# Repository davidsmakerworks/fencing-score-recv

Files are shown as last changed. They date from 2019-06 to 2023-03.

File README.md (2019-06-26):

# fencing-score-recv
Remote fencing scoring light display receiver

This is the receiver portion of the [remote fencing scoring light display](https://github.com/davidsmakerworks/fencing-score-xmit) project. This is designed to be placed on the wall at the ends of the fencing strip. It includes a timer to automatically turn off the lights if no shutoff signal is received from the transmitter within a reasonable amount of time.

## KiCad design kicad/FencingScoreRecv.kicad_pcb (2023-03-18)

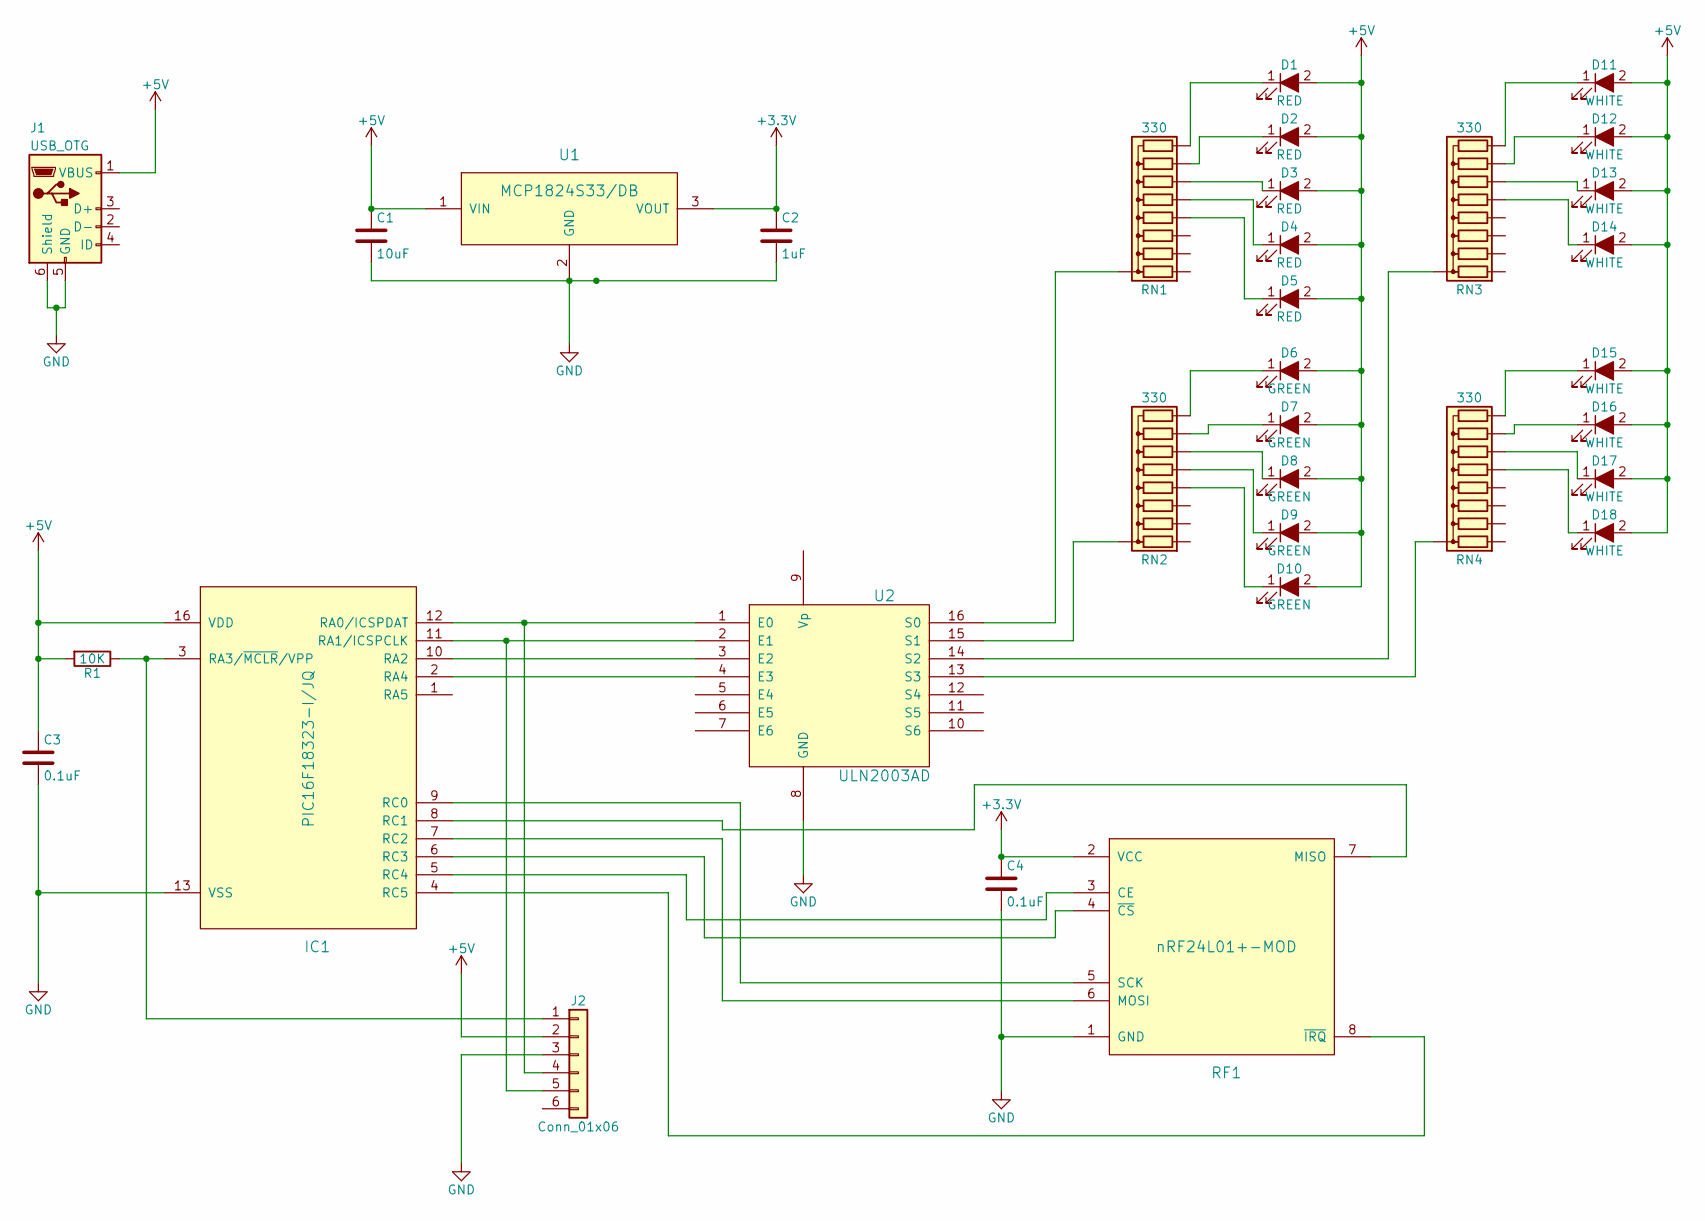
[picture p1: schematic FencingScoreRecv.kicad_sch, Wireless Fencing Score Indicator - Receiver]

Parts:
C1: 10uF; C_0805
C2: 1uF; C_0805
C3, C4: 0.1uF; C_0603
D1, D2, D3, D4, D5: RED; LED_D5.0mm
D6, D7, D8, D9, D10: GREEN; LED_D5.0mm
D11, D12, D13, D14, D15, D16, D17, D18: WHITE; LED_D5.0mm
IC1: PIC16F18323-I/JQ; QFN-16-1EP_4x4mm_Pitch0.65mm
J1: USB_OTG; Molex_105164-0001_MicroUSB
J2: Conn_01x06; Pin_Header_Straight_1x06_Pitch2.54mm
R1: 10K; R_0805
RF1: nRF24L01+-MOD; nRF24L01+-Module
RN1, RN2, RN3, RN4: 330; R_Array_SIP9
U1: MCP1824S33/DB; SOT-223
U2: ULN2003AD; SOIC-16_3.9x9.9mm_Pitch1.27mm

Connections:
+3V3: C2.1, C4.1, RF1.2 (VCC), U1.3 (VOUT)
+5V: C1.1, C3.1, D1.2 (A), D2.2 (A), D3.2 (A), D4.2 (A), D5.2 (A), D6.2 (A), D7.2 (A), D8.2 (A), D9.2 (A), D10.2 (A), D11.2 (A), D12.2 (A), D13.2 (A), D14.2 (A), D15.2 (A), D16.2 (A), D17.2 (A), D18.2 (A), IC1.16 (VDD), J1.1 (VBUS), J2.2, R1.2, U1.1 (VIN); also elsewhere on the board
unnamed: D1.1 (K), RN1.9 (R8)
unnamed: D2.1 (K), RN1.8 (R7)
unnamed: D3.1 (K), RN1.7 (R6)
unnamed: D4.1 (K), RN1.6 (R5)
unnamed: D5.1 (K), RN1.5 (R4)
unnamed: D6.1 (K), RN2.9 (R8)
unnamed: D7.1 (K), RN2.8 (R7)
unnamed: D8.1 (K), RN2.7 (R6)
unnamed: D9.1 (K), RN2.6 (R5)
unnamed: D10.1 (K), RN2.5 (R4)
unnamed: D11.1 (K), RN3.9 (R8)
unnamed: D12.1 (K), RN3.8 (R7)
unnamed: D13.1 (K), RN3.7 (R6)
unnamed: D14.1 (K), RN3.6 (R5)
unnamed: D15.1 (K), RN4.9 (R8)
unnamed: D16.1 (K), RN4.8 (R7)
unnamed: D17.1 (K), RN4.7 (R6)
unnamed: D18.1 (K), RN4.6 (R5)
unnamed: IC1.2 (RA4), U2.4 (E3)
unnamed 22: IC1.3 (RA3/~MCLR/VPP), J2.1, R1.1; also elsewhere on the board
unnamed: IC1.4 (RC5), RF1.8 (~IRQ)
unnamed: IC1.5 (RC4), RF1.3 (CE)
unnamed: IC1.6 (RC3), RF1.4 (~CS)
unnamed: IC1.7 (RC2), RF1.6 (MOSI)
unnamed: IC1.8 (RC1), RF1.7 (MISO)
unnamed: IC1.9 (RC0), RF1.5 (SCK)
unnamed: IC1.10 (RA2), U2.3 (E2)
unnamed 30: IC1.11 (RA1/ICSPCLK), J2.5, U2.2 (E1); also elsewhere on the board
unnamed 31: IC1.12 (RA0/ICSPDAT), J2.4, U2.1 (E0); also elsewhere on the board
unnamed: RN1.1 (common), U2.16 (S0)
unnamed: RN2.1 (common), U2.15 (S1)
unnamed: RN3.1 (common), U2.14 (S2)
unnamed: RN4.1 (common), U2.13 (S3)

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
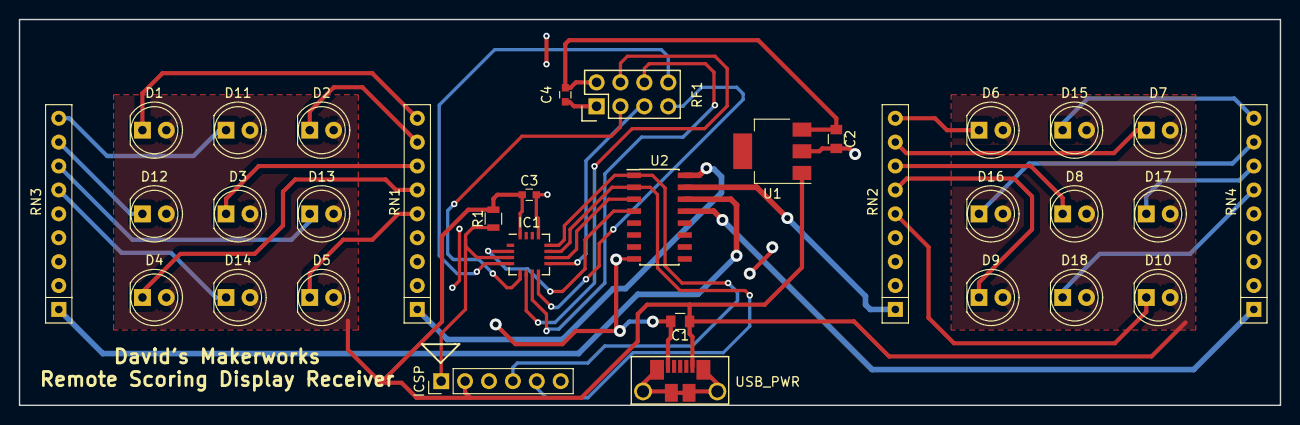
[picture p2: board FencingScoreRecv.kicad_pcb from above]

Board: 2 copper layers, 134.0 x 41.0 mm, 33 parts (0 on the bottom side), 36 nets.

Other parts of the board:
ICSP: Conn_01x06; Pin_Header_Straight_1x06_Pitch2.54mm
USB_PWR: USB_OTG; Molex_105164-0001_MicroUSB

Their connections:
+5V: ICSP.2, USB_PWR.1; also elsewhere on the board
unnamed 22: ICSP.1; also elsewhere on the board
unnamed 30: ICSP.5; also elsewhere on the board
unnamed 31: ICSP.4; also elsewhere on the board

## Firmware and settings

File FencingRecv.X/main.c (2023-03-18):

/*
 * Remote Fencing Score Display - Receiver
 * Copyright (c) 2019 David Rice
 *
 * Designed for PIC16F18323 or PIC16F18325
 * 
 * Interfaces with nRF24L01+ 2.4 GHz RF module for transmission
 *
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
 * THE SOFTWARE IS PROVIDED "AS IS", WITHOUT WARRANTY OF ANY KIND, EXPRESS OR
 * IMPLIED, INCLUDING BUT NOT LIMITED TO THE WARRANTIES OF MERCHANTABILITY,
 * FITNESS FOR A PARTICULAR PURPOSE AND NONINFRINGEMENT. IN NO EVENT SHALL THE
 * AUTHORS OR COPYRIGHT HOLDERS BE LIABLE FOR ANY CLAIM, DAMAGES OR OTHER
 * LIABILITY, WHETHER IN AN ACTION OF CONTRACT, TORT OR OTHERWISE, ARISING FROM,
 * OUT OF OR IN CONNECTION WITH THE SOFTWARE OR THE USE OR OTHER DEALINGS IN THE
 * SOFTWARE.
 */

// PIC16F18323 Configuration Bit Settings

// 'C' source line config statements

// CONFIG1
#pragma config FEXTOSC = OFF    // FEXTOSC External Oscillator mode Selection bits (Oscillator not enabled)
#pragma config RSTOSC = HFINT1  // Power-up default value for COSC bits (HFINTOSC (1MHz))
#pragma config CLKOUTEN = OFF   // Clock Out Enable bit (CLKOUT function is disabled; I/O or oscillator function on OSC2)
#pragma config CSWEN = ON       // Clock Switch Enable bit (Writing to NOSC and NDIV is allowed)
#pragma config FCMEN = OFF      // Fail-Safe Clock Monitor Enable (Fail-Safe Clock Monitor is disabled)

// CONFIG2
#pragma config MCLRE = ON       // Master Clear Enable bit (MCLR/VPP pin function is MCLR; Weak pull-up enabled)
#pragma config PWRTE = ON       // Power-up Timer Enable bit (PWRT enabled)
#pragma config WDTE = OFF       // Watchdog Timer Enable bits (WDT disabled; SWDTEN is ignored)
#pragma config LPBOREN = OFF    // Low-power BOR enable bit (ULPBOR disabled)
#pragma config BOREN = ON       // Brown-out Reset Enable bits (Brown-out Reset enabled, SBOREN bit ignored)
#pragma config BORV = LOW       // Brown-out Reset Voltage selection bit (Brown-out voltage (Vbor) set to 2.45V)
#pragma config PPS1WAY = ON     // PPSLOCK bit One-Way Set Enable bit (The PPSLOCK bit can be cleared and set only once; PPS registers remain locked after one clear/set cycle)
#pragma config STVREN = ON      // Stack Overflow/Underflow Reset Enable bit (Stack Overflow or Underflow will cause a Reset)
#pragma config DEBUG = OFF      // Debugger enable bit (Background debugger disabled)

// CONFIG3
#pragma config WRT = OFF        // User NVM self-write protection bits (Write protection off)
#pragma config LVP = ON         // Low Voltage Programming Enable bit (Low Voltage programming enabled. MCLR/VPP pin function is MCLR. MCLRE configuration bit is ignored.)

// CONFIG4
#pragma config CP = OFF         // User NVM Program Memory Code Protection bit (User NVM code protection disabled)
#pragma config CPD = OFF        // Data NVM Memory Code Protection bit (Data NVM code protection disabled)

// #pragma config statements should precede project file includes.
// Use project enums instead of #define for ON and OFF.

#include <xc.h>
#include <stdint.h>
#include <stdbool.h>

#include "nRF24L01P.h"
#include "nRF24L01P-cfg.h"

/* ===== CONFIGURABLE OPTIONS START HERE ===== */
#define RF_CHANNEL      0x0CU
#define RF_RX_ADDR      strip2_addr
/* ====== CONFIGURABLE OPTIONS END HERE ====== */

#define _XTAL_FREQ      4000000

#define ADDR_LEN        5
#define PAYLOAD_WIDTH   1

#define LEFT_RED_LED    LATAbits.LATA0
#define RIGHT_GREEN_LED LATAbits.LATA1
#define LEFT_WHITE_LED  LATAbits.LATA2
#define RIGHT_WHITE_LED LATAbits.LATA4

#define LEFT_RED_MASK       0b00110000
#define RIGHT_GREEN_MASK    0b00001100
#define LEFT_WHITE_MASK     0b11000000
#define RIGHT_WHITE_MASK    0b00000011

const uint8_t strip1_addr[ADDR_LEN] = { 0x44, 0x4D, 0x57, 0x31, 0xAA };
const uint8_t strip2_addr[ADDR_LEN] = { 0x44, 0x4D, 0x57, 0x31, 0xBB };
const uint8_t mask1_addr[ADDR_LEN] = { 0x44, 0x4D, 0x57, 0x31, 0xCC };
const uint8_t mask2_addr[ADDR_LEN] = { 0x44, 0x4D, 0x57, 0x31, 0xDD };

volatile bool data_pending = false;

void __interrupt() isr(void) {
    /* Do NOT check PEIE in ISR because TMR0 and INT are not gated by PEIE */
    
    /* If external interrupt fires, data has been received by the RF module */
    if (PIE0bits.INTE && PIR0bits.INTF) {
        PIR0bits.INTF = 0;
        
        data_pending = true;
    }
    
    /* If timer interrupt fires, turn off all lights and stop timer */
    if (PIE0bits.TMR0IE && PIR0bits.TMR0IF) {
        PIR0bits.TMR0IF = 0;
        
        LEFT_RED_LED = 0;
        RIGHT_GREEN_LED = 0;
        LEFT_WHITE_LED = 0;
        RIGHT_WHITE_LED = 0;

        T0CON0bits.T0EN = 0;
    }
}

uint8_t transfer_spi(uint8_t data) {
    SSP1BUF = data;
    
    while (!SSP1STATbits.BF);
    
    data = SSP1BUF;
    
    return data;
}

void init_ports(void) {
    /* Disable all analog features */
    ANSELA = 0x00;
    ANSELC = 0x00;
    
    /* Initialize all ports as outputs except RC1 (SDI) and RC5 (RF_IRQ) */
    TRISA = 0x00;
    TRISC = _TRISC_TRISC1_MASK | _TRISC_TRISC5_MASK;
    
    /* Pull all outputs low except RF_CSN */
    LATA = 0x00;
    LATC = _LATC_LATC3_MASK;
    
    /* Set TTL input level on RC1 (SDI1) and RC5 (RF_IRQ) */
    INLVLCbits.INLVLC1 = 0;
    INLVLCbits.INLVLC5 = 0;
}

void init_osc(void) { 
    /* Set frequency of HFINTOSC to 4 MHz */
    OSCFRQbits.HFFRQ = 0b0011;
    
    /* Set clock divider to 1:1 to achieve Fosc of 4 MHz */
    OSCCON1bits.NDIV = 0b0000;
}

void init_spi(void) {
    /* Set MSSP1 to SPI Master mode, clock = Fosc / 4 = 1 MHz at Fosc = 4 MHz */
    SSP1CON1bits.SSPM = 0b0000;
    
    /* Transmit data on active-to-idle transition */
    SSP1STATbits.CKE = 1;
    
    /* Enable MSSP1 */
    SSP1CON1bits.SSPEN = 1;
}

void init_pps(void) {
    bool state;
    
    /* Preserve global interrupt state and disable interrupts */
    state = INTCONbits.GIE;
    INTCONbits.GIE = 0;
    
    /* Unlock PPS */
    PPSLOCK = 0x55;
    PPSLOCK = 0xAA;
    PPSLOCKbits.PPSLOCKED = 0;
    
    /* SCK1 on RC0 */
    RC0PPS = 0b11000;
    
    /* SDI1 on RC1 */
    SSP1DATPPS = 0b10001;
    
    /* SDO1 on RC2 */
    RC2PPS = 0b11001;
    
    /* INT on RC5 */
    INTPPS = 0b10101;
    
    /* Lock PPS */
    PPSLOCK = 0x55;
    PPSLOCK = 0xAA;
    PPSLOCKbits.PPSLOCKED = 1;
    
    /* Restore global interrupt state */
    INTCONbits.GIE = state;
}

void init_interrupts(void) {
    /* Interrupt on falling edge of external interrupt pin */
    INTCONbits.INTEDG = 0;
    
    /* Enable external interrupt */
    PIE0bits.INTE = 1;
    
    /* Enable Timer0 interrupt */
    PIE0bits.TMR0IE = 1;
}

void init_rf(void) {
    /* Allow for maximum possible RF module startup time */
    __delay_ms(100);
    
    /* Set 1-byte payload width */
    nrf24_write_register(NRF24_RX_PW_P0, PAYLOAD_WIDTH);
    
    /* Set RF power to 0 dBm and data rate to 1 Mbit/Sec */
    nrf24_write_register(NRF24_RF_SETUP, NRF24_RF_PWR_0DBM);
    
    /* Set 5-byte address width */
    nrf24_write_register(NRF24_SETUP_AW, NRF24_AW_5);
    
    /* Set initial RF channel */
    nrf24_write_register(NRF24_RF_CH, RF_CHANNEL);
    
    /* Enable receive on pipe 0 only */
    nrf24_write_register(NRF24_EN_RXADDR, NRF24_ERX_P0);
    
    /* Set receive address  */
    nrf24_write_register_multi(NRF24_RX_ADDR_P0, RF_RX_ADDR, ADDR_LEN);
    
    /* Mask RX_DR interrupt on RF module, enable CRC, power up RF module in transmit-standby mode */
    nrf24_write_register(NRF24_CONFIG, NRF24_MASK_TX_DS | NRF24_MASK_MAX_RT | NRF24_EN_CRC | NRF24_PWR_UP | NRF24_PRIM_RX);
    
    /* Clear any pending RF module interrupts */
    nrf24_write_register(NRF24_STATUS, NRF24_TX_DS | NRF24_MAX_RT | NRF24_RX_DR);
}

void init_timer(void) {
    /* Set Timer0 clock source to HFINTOSC so timer will run during sleep */
    T0CON1bits.T0CS = 0b011;

    /* Set Timer0 prescaler to 1:32768 = 122.1 ticks/sec at HFINTOSC = 4 MHz */
    T0CON1bits.T0CKPS = 0b1111;
    
    /* Timer0 runs asynchronously to allow operation during sleep */
    T0CON1bits.T0ASYNC = 1;
    
    /* Set Timer0 postscaler to 1:4 for approximately 8.4 second interrupt time */
    T0CON0bits.T0OUTPS = 0b0011;
    
    /* Set Timer0 period to maximum (TMR0H is timer period in 8-bit mode) */
    TMR0H = 0xFF;
    TMR0L = 0x00;
}

void main(void) {
    uint8_t buf;
    
    /* Initialize peripherals */
    init_ports();
    init_osc();
    init_timer();
    init_pps();
    init_spi();
    init_interrupts();
    init_rf();
    
    /* Clear any spurious external interrupt request */
    PIR0bits.INTF = 0;
    
    /* Enable global interrupts */
    INTCONbits.GIE = 1;
    
    NRF24_CE_ACTIVE();
    
    while(1) {       
        SLEEP();
        
        if (data_pending) {
            nrf24_read_payload(&buf, PAYLOAD_WIDTH);

            if (buf & LEFT_RED_MASK)
            {
                LEFT_RED_LED = 1;
            } else {
                LEFT_RED_LED = 0;
            }

            if (buf & RIGHT_GREEN_MASK)
            {
                RIGHT_GREEN_LED = 1;
            } else {
                RIGHT_GREEN_LED = 0;
            }

            if (buf & LEFT_WHITE_MASK)
            {
                LEFT_WHITE_LED = 1;
            } else {
                LEFT_WHITE_LED = 0;
            }

            if (buf & RIGHT_WHITE_MASK)
            {
                RIGHT_WHITE_LED = 1;
            } else {
                RIGHT_WHITE_LED = 0;
            }  

            nrf24_write_register(NRF24_STATUS, NRF24_RX_DR);
            
            if (buf != 0x00) {
                TMR0L = 0x00;
                T0CON0bits.T0EN = 1;
            } else {
                T0CON0bits.T0EN = 0;
            }
            
            data_pending = false;
        }
    }
}

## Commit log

2019-06-26 Update for compatibility with restructured driver
2020-11-16 Update data block
    [FencingScoreRecv.kicad_pcb]
2023-03-18 Update RF addr and silkscreen, update for KiCad 7
    [FencingScoreRecv.kicad_pcb, FencingScoreRecv.kicad_sch]
